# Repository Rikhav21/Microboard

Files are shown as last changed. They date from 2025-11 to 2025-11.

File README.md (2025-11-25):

# Microboard
# About
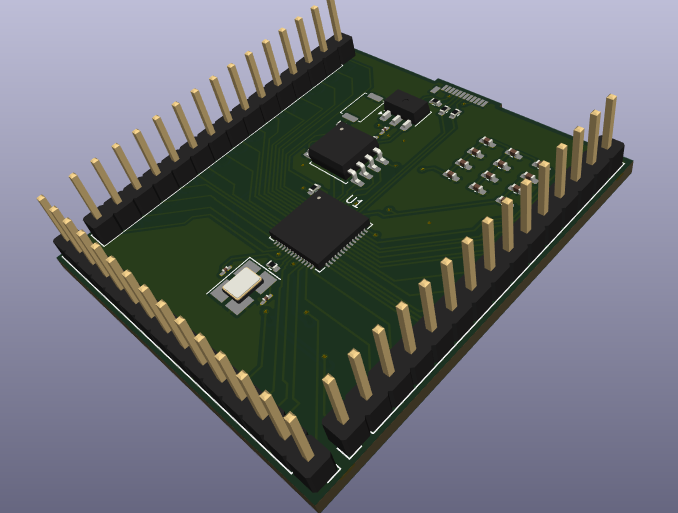
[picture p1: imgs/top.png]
So this is a devboard that I made because I lose wires to upload code to my arduinos all the time, so I just wanted to make a devboard where you can just plug it into the computer, and run suff. So one that that you will probably notice it that I swapped out the USB recepticle for a USB plug, and I also just tried to utilize as much of the IO as possible. Also I think that I never actually saw a squre devboard, so I also tried to make it a unique shape. In the rengers you can not see the USB-C plug, so I will update with pictures when I actually build it. 
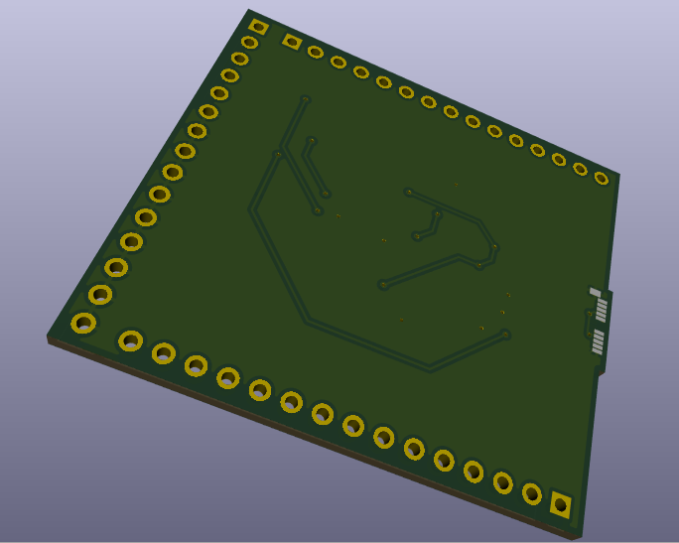
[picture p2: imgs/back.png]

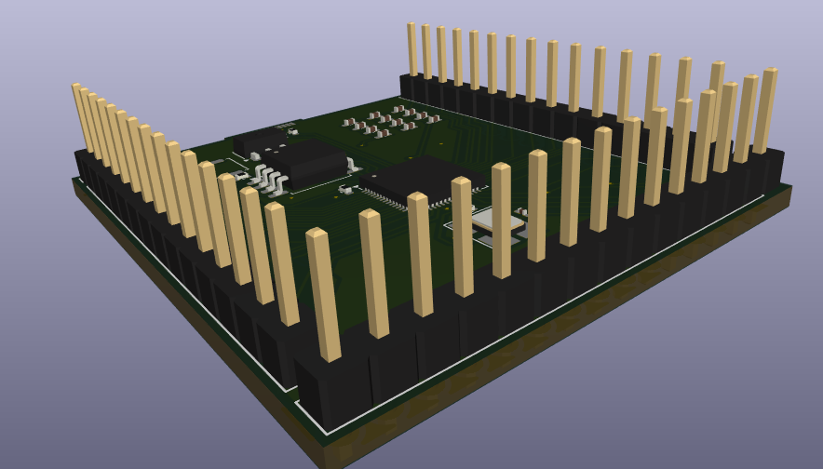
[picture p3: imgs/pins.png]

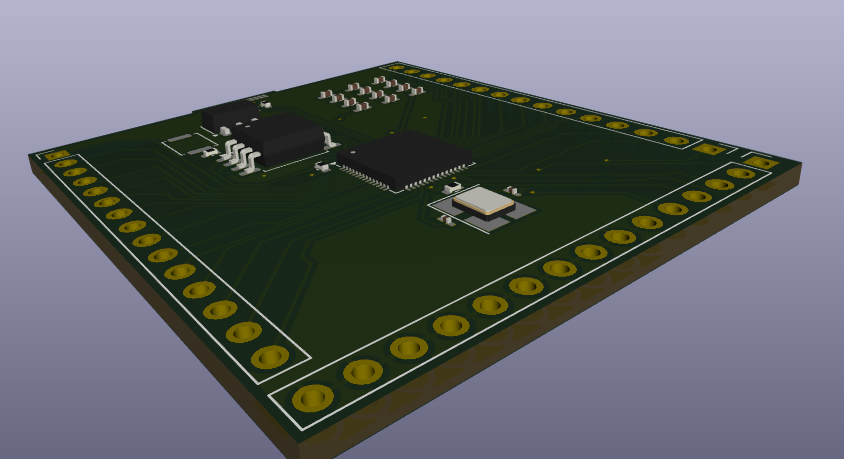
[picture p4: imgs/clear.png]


# Schematic
So hile making the schematic, I think that it looks pretty similar to most other devboards. As I said before, I tried to use all of the pins on the MUCH, so everything is used.
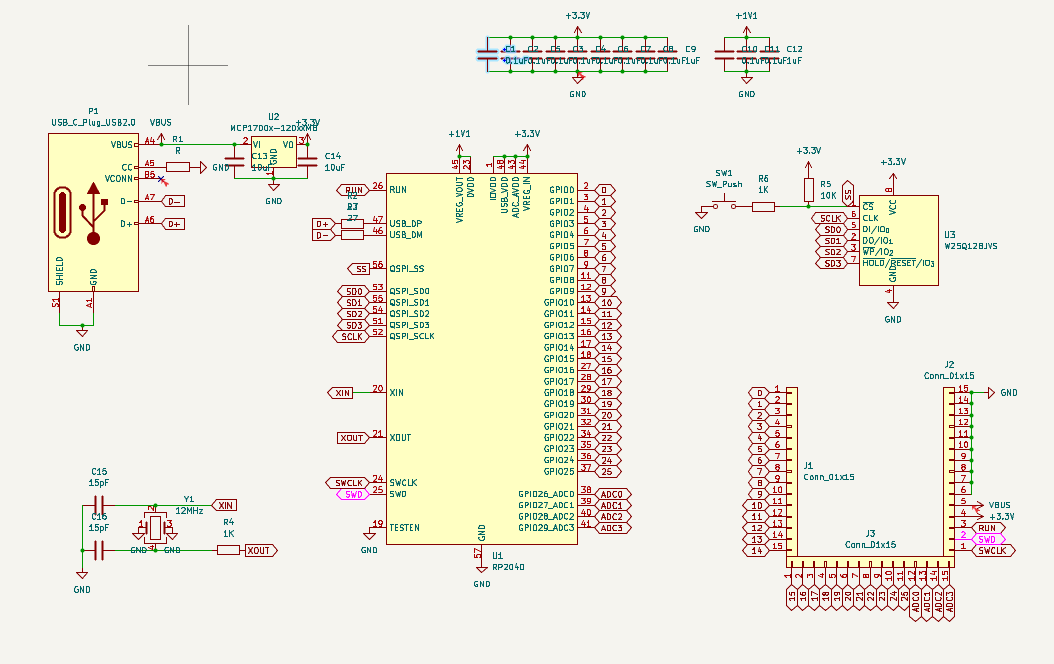
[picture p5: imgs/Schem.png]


# PCB
This was actually my first time using vias, and having to reroute something so many times. It was also my first time uring pours, but that made it a lot easier. I tried to get most of the routing done on the front, but there are some vias to the back of the PCB.
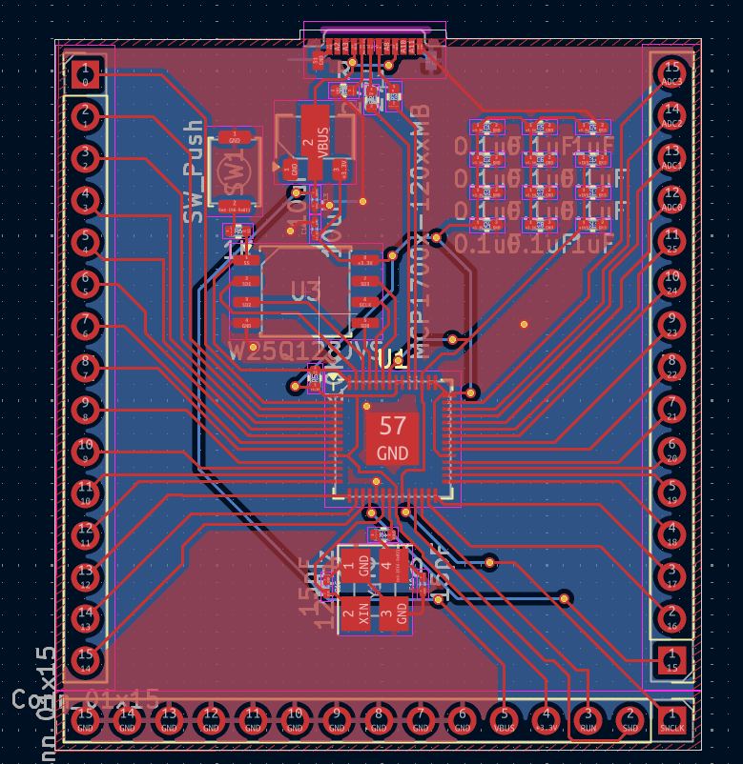
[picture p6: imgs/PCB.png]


# Making
So for building this I am ordering the PCB from JLCPCB and all of the other components from LCSC. I am going to hald solder all of the components, but you could do PCBA. The cost should be around $26, but that is counting all of the MOQs, realistically you coulb proabably make 5 of them while spending less than $39 and the majority of the cost is in shipping.

# BOM
| Mfr. | Order Qty. | Unit Price(USD) | Ext. Price(USD) | Package | Description | Product Link |
|---|---|---|---|---|---|---|
| Samsung Electro-Mechanics | 20 | 0.0101 | 0.20 | 0805 | 10uF 0805 Ceramic Capacitors | [Link](https://www.lcsc.com/product-detail/C15850.html) |
| FH | 100 | 0.0031 | 0.31 | 0603 | 15pF 0603 Ceramic Capacitors | [Link](https://www.lcsc.com/product-detail/C91703.html) |
| Raspberry Pi | 1 | 0.9440 | 0.94 | LQFN-56(7x7) |  | [Link](https://www.lcsc.com/product-detail/C2040.html) |
| Hong Cheng | 5 | 0.0805 | 0.40 | Through Hole, Right Angle, P=2.54mm | Right Angle, P=2.54mm Headers, Male Pins RoHS | [Link](https://www.lcsc.com/product-detail/C41376120.html) |
| YAGEO | 100 | 0.0006 | 0.06 | 0402 | 10kΩ 0402 Resistor | [Link](https://www.lcsc.com/product-detail/C60490.html) |
| YAGEO | 100 | 0.0006 | 0.06 | 0402 | 1kΩ 0402 Resistor | [Link](https://www.lcsc.com/product-detail/C106235.html) |
| Huiyuan crystal | 10 | 0.0603 | 0.60 | SMD3225-4P | Crystal Oscillator 20pF SMD3225-4P | [Link](https://www.lcsc.com/product-detail/C5265859.html) |
| Winbond | 1 | 1.6062 | 1.61 | SOIC-8-208mil | 128Mbit 2.7V~3.6V 133MHz SPI SOIC-8 | [Link](https://www.lcsc.com/product-detail/C97521.html) |
| UNI-ROYAL | 100 | 0.0006 | 0.06 | 0402 | 27Ω 0402 Resistor | [Link](https://www.lcsc.com/product-detail/C25100.html) |
| UNI-ROYAL | 100 | 0.0005 | 0.05 | 0402 | 5.1kΩ 0402 Resistor | [Link](https://www.lcsc.com/product-detail/C25905.html) |
| YAGEO | 100 | 0.0009 | 0.09 | 0402 | 100nF 0402 Ceramic Capacitors | [Link](https://www.lcsc.com/product-detail/C60474.html) |
| ALPSALPINE | 5 | 0.1277 | 0.64 | SMD, 3.9x2.9mm | Round Button 3.9mm SPST | [Link](https://www.lcsc.com/product-detail/C115357.html) |
| Samsung Electro-Mechanics | 100 | 0.0030 | 0.30 | 0402 | 25V 1uF X5R ±10% 0402 Ceramic Capacitors RoHS | [Link](https://www.lcsc.com/product-detail/C52923.html) |
| MICROCHIP | 1 | 0.5422 | 0.54 | SOT-89-3 | Fixed 3.3V SOT-89-3 Voltage Regulator | [Link](https://www.lcsc.com/product-detail/C632000.html) |
| MOLEX | 1 | 1.1995 | 1.20 | SMD | 1 24P -30℃~+85℃ Type-C SMD USB | [Link](https://www.lcsc.com/product-detail/C561769.html) |
|PCB+Shipping  |  |  |$5.12  |  |  |  |
|LCSC shipping + handling total  | ||$18.59  |  |  |  |
|Total  |  |  |$25.28 |  |  |  |

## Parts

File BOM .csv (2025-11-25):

Mrf# | Mfr. | Order Qty. | Unit Price(USD) | Ext.Price(USD) | LCSC# | Package | Description | Product Link
CL21A106KAYNNNE | Samsung Electro-Mechanics | 20 | 0.0101 | 0.20 | C15850 | 0805 | 10uF 0805 Ceramic Capacitors | https://www.lcsc.com/product-detail/C15850.html
0603CG150J500NT | FH | 100 | 0.0031 | 0.31 | C91703 | 0603 | 15pF 0603 Ceramic Capacitors | https://www.lcsc.com/product-detail/C91703.html
RP2040 | Raspberry Pi | 1 | 0.9440 | 0.94 | C2040 | LQFN-56(7x7) |  | https://www.lcsc.com/product-detail/C2040.html
HC-PZ254-13.8L-1x15PWA | Hong Cheng | 5 | 0.0805 | 0.40 | C41376120 | Through Hole,Right Angle,P=2.54mm | Right Angle,P=2.54mm Headers, Male Pins RoHS | https://www.lcsc.com/product-detail/C41376120.html
RC0402FR-0710KL | YAGEO | 100 | 0.0006 | 0.06 | C60490 | 0402 | 10kΩ 0402 Resistor | https://www.lcsc.com/product-detail/C60490.html
RC0402FR-071KL | YAGEO | 100 | 0.0006 | 0.06 | C106235 | 0402 | 1kΩ 0402 Resistor | https://www.lcsc.com/product-detail/C106235.html
HY12MSMD3225OB1R30 | Huiyuan crystal | 10 | 0.0603 | 0.60 | C5265859 | SMD3225-4P | Crystal Oscillator 20pF SMD3225-4P | https://www.lcsc.com/product-detail/C5265859.html
W25Q128JVSIQ | Winbond | 1 | 1.6062 | 1.61 | C97521 | SOIC-8-208mil | 128Mbit 2.7V~3.6V 133MHz SPI SOIC -8 | https://www.lcsc.com/product-detail/C97521.html
0402WGF270JTCE | UNI-ROYAL | 100 | 0.0006 | 0.06 | C25100 | 0402 | 27Ω 0402 Resistor | https://www.lcsc.com/product-detail/C25100.html
0402WGF5101TCE | UNI-ROYAL | 100 | 0.0005 | 0.05 | C25905 | 0402 | 5.1kΩ 0402 Resistor | https://www.lcsc.com/product-detail/C25905.html
CC0402KRX7R7BB104 | YAGEO | 100 | 0.0009 | 0.09 | C60474 | 0402 | 100nF 0402 Ceramic Capacitors | https://www.lcsc.com/product-detail/C60474.html
SKRKAEE020 | ALPSALPINE | 5 | 0.1277 | 0.64 | C115357 | SMD,3.9x2.9mm | Round Button 3.9mm SPST | https://www.lcsc.com/product-detail/C115357.html
CL05A105KA5NQNC | Samsung Electro-Mechanics | 100 | 0.0030 | 0.30 | C52923 | 0402 | 25V 1uF X5R ±10% 0402 Ceramic Capacitors RoHS | https://www.lcsc.com/product-detail/C52923.html
MCP1700T-3302E/MB | MICROCHIP | 1 | 0.5422 | 0.54 | C632000 | SOT-89-3 | Fixed 3.3V SOT-89-3 Voltage Regulator | https://www.lcsc.com/product-detail/C632000.html
1054440011 | MOLEX | 1 | 1.1995 | 1.20 | C561769 | SMD | 1 24P -30℃~+85℃ Type-C SMD USB | https://www.lcsc.com/product-detail/C561769.html
We also need to buy the PCB ($2) + shipping = $5.12
Also for shipping+ handling for LCSC the total becomes $18.59
Finally, after adding tax you get | $25.28

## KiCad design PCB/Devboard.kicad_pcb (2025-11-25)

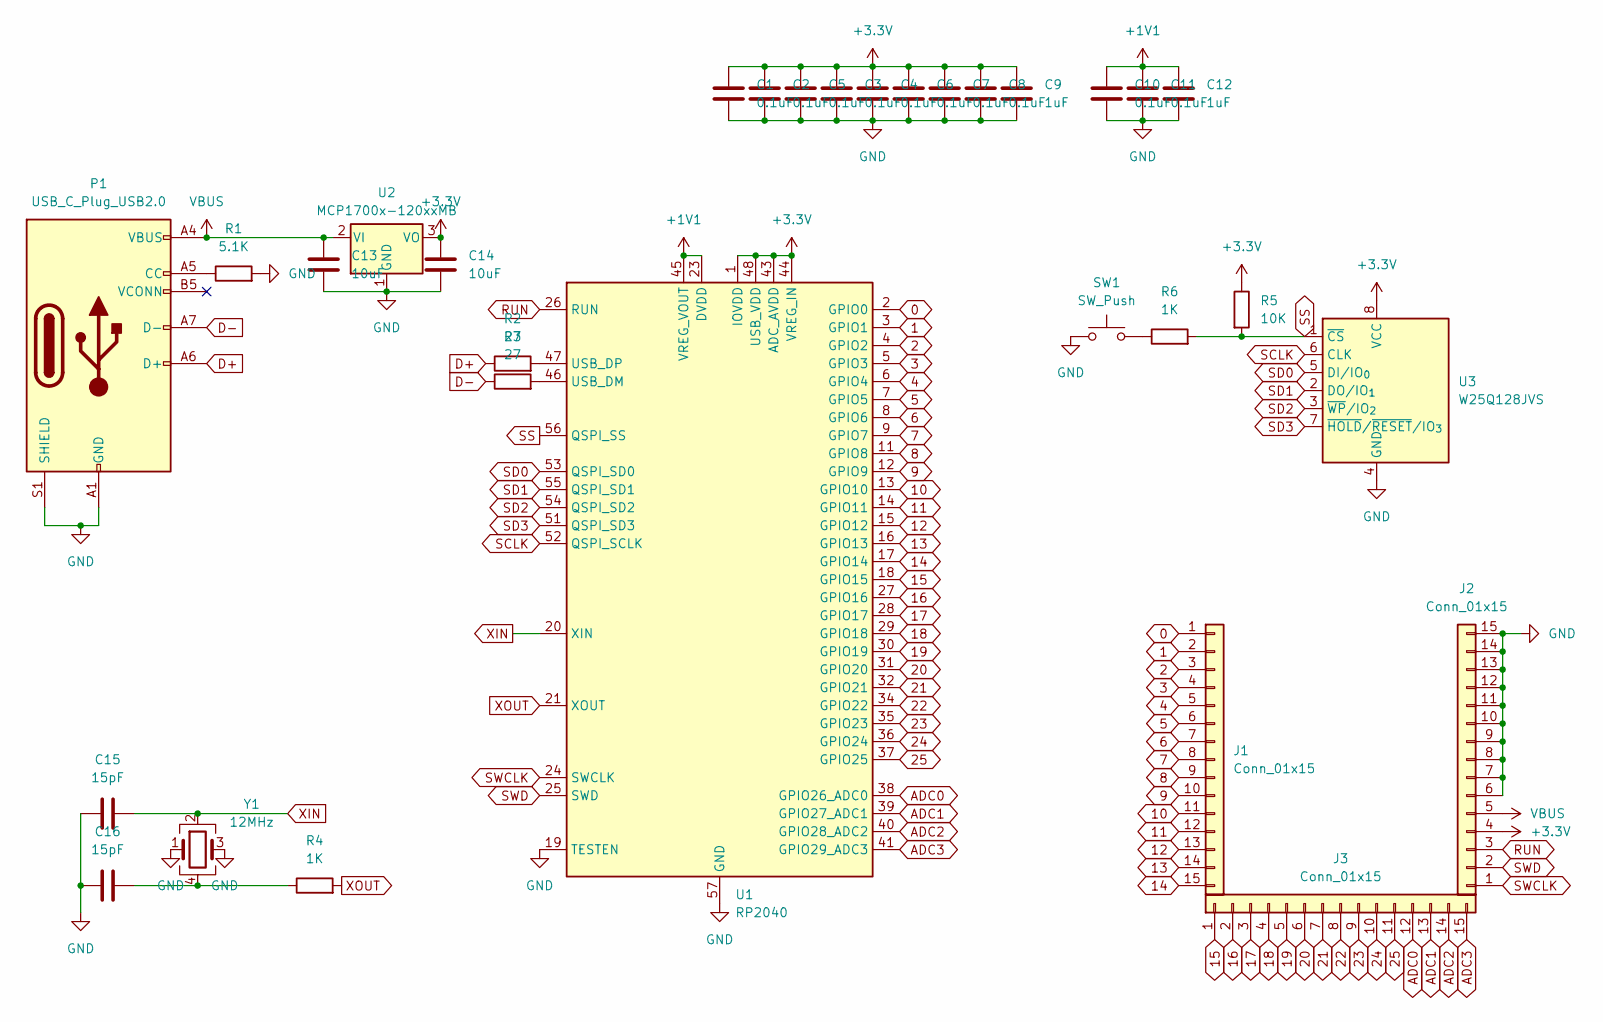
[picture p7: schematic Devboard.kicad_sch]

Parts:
C1, C2, C3, C4, C5, C6, C7, C8, C10, C11: 0.1uF; C_0402_1005Metric_Pad0.74x0.62mm_HandSolder
C9, C12: 1uF; C_0402_1005Metric_Pad0.74x0.62mm_HandSolder
C13, C14: 10uF; C_0201_0603Metric_Pad0.64x0.40mm_HandSolder
C15, C16: 15pF; C_0201_0603Metric_Pad0.64x0.40mm_HandSolder
J1, J2, J3: Conn_01x15; PinHeader_1x15_P2.54mm_Vertical
P1: USB_C_Plug_USB2.0; USB_C_Plug_ShenzhenJingTuoJin_918-118A2021Y40002_Vertical
R1: 5.1K; R_0402_1005Metric
R2, R3: 27; R_0402_1005Metric
R4, R6: 1K; R_0402_1005Metric
R5: 10K; R_0402_1005Metric
SW1: SW_Push; SW_Push_SPST_NO_Alps_SKRK
U1: RP2040; QFN-56-1EP_7x7mm_P0.4mm_EP3.2x3.2mm
U2: MCP1700x-120xxMB; SOT-89-3
U3: W25Q128JVS; SOIC-8_5.3x5.3mm_P1.27mm
Y1: 12MHz; Crystal_SMD_3225-4Pin_3.2x2.5mm_HandSoldering

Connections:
0: J1.1, U1.2 (GPIO0)
1: J1.2, U1.3 (GPIO1)
2: J1.3, U1.4 (GPIO2)
3: J1.4, U1.5 (GPIO3)
4: J1.5, U1.6 (GPIO4)
5: J1.6, U1.7 (GPIO5)
6: J1.7, U1.8 (GPIO6)
7: J1.8, U1.9 (GPIO7)
8: J1.9, U1.11 (GPIO8)
9: J1.10, U1.12 (GPIO9)
10: J1.11, U1.13 (GPIO10)
11: J1.12, U1.14 (GPIO11)
12: J1.13, U1.15 (GPIO12)
13: J1.14, U1.16 (GPIO13)
14: J1.15, U1.17 (GPIO14)
15: J3.1, U1.18 (GPIO15)
16: J3.2, U1.27 (GPIO16)
17: J3.3, U1.28 (GPIO17)
18: J3.4, U1.29 (GPIO18)
19: J3.5, U1.30 (GPIO19)
20: J3.6, U1.31 (GPIO20)
21: J3.7, U1.32 (GPIO21)
22: J3.8, U1.34 (GPIO22)
23: J3.9, U1.35 (GPIO23)
24: J3.10, U1.36 (GPIO24)
25: J3.11, U1.37 (GPIO25)
+1V1: C10.1, C11.1, C12.1, U1.23 (DVDD), U1.45 (VREG_VOUT), U1.50 (DVDD)
+3.3V: C1.1, C2.1, C3.1, C4.1, C5.1, C6.1, C7.1, C8.1, C9.1, C14.1, J2.4, R5.1, U1.1 (IOVDD), U1.10 (IOVDD), U1.22 (IOVDD), U1.33 (IOVDD), U1.42 (IOVDD), U1.43 (ADC_AVDD), U1.44 (VREG_IN), U1.48 (USB_VDD), U1.49 (IOVDD), U2.3 (VO), U3.8 (VCC)
ADC0: J3.12, U1.38 (GPIO26_ADC0)
ADC1: J3.13, U1.39 (GPIO27_ADC1)
ADC2: J3.14, U1.40 (GPIO28_ADC2)
ADC3: J3.15, U1.41 (GPIO29_ADC3)
D+: P1.A6 (D+), R2.1
D-: P1.A7 (D-), R3.1
GND: C1.2, C2.2, C3.2, C4.2, C5.2, C6.2, C7.2, C8.2, C9.2, C10.2, C11.2, C12.2, C13.2, C14.2, C15.1, C16.1, J2.6, J2.7, J2.8, J2.9, J2.10, J2.11, J2.12, J2.13, J2.14, J2.15, P1.A1 (GND), P1.A12 (GND), P1.B1 (GND), P1.B12 (GND), P1.S1 (SHIELD), R1.2, SW1.1, U1.19 (TESTEN), U1.57 (GND), U2.1 (GND), U3.4 (GND), Y1.1, Y1.3
unnamed: C16.2, R4.1, Y1.4
unnamed: P1.A5 (CC), R1.1
unnamed: R6.1, SW1.2
unnamed: R3.2, U1.46 (USB_DM)
unnamed: R2.2, U1.47 (USB_DP)
RUN: J2.3, U1.26 (RUN)
SCLK: U1.52 (QSPI_SCLK), U3.6 (CLK)
SD0: U1.53 (QSPI_SD0), U3.5 (DI/IO_{0})
SD1: U1.55 (QSPI_SD1), U3.2 (DO/IO_{1})
SD2: U1.54 (QSPI_SD2), U3.3 (~WP/IO_{2})
SD3: U1.51 (QSPI_SD3), U3.7 (~HOLD/~RESET/IO_{3})
SS: R5.2, R6.2, U1.56 (QSPI_SS), U3.1 (~CS)
SWCLK: J2.1, U1.24 (SWCLK)
SWD: J2.2, U1.25 (SWD)
VBUS: C13.1, J2.5, P1.A4 (VBUS), P1.A9 (VBUS), P1.B4 (VBUS), P1.B9 (VBUS), U2.2 (VI)
XIN: C15.2, U1.20 (XIN), Y1.2
XOUT: R4.2, U1.21 (XOUT)

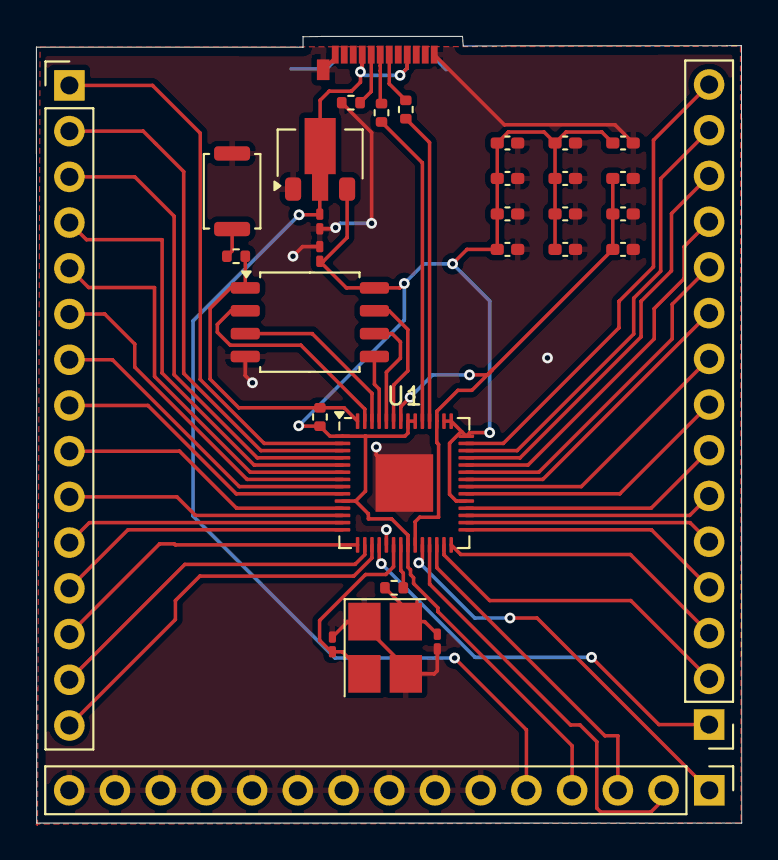
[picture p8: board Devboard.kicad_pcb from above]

Board: 2 copper layers, 39.2 x 43.7 mm, 31 parts (0 on the bottom side), 52 nets.

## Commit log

2025-11-25 Update and rename Full_BOM - sheet1 (1).csv to BOM .csv
    [BOM .csv]
2025-11-25 Expand README with project details and BOM
    Added detailed sections about the project, including the about, schematic, PCB, making process, and BOM with links to components.
